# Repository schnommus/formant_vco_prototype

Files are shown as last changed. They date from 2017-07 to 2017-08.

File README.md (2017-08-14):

# SMD Formant VCO Prototype
KiCAD files for eurorack-compatible formant-based VCO design. Mostly created just to learn KiCAD.

Video on construction/operation is here: https://www.youtube.com/watch?v=rq4ovZ2om6k

## ERRATA [V1A] (To be fixed in future revision)
- The TL071 op-amp in the CAD files is arbitrary, I actually used an LM358. Just use whatever 8-pin SOIC dual op-amp you like.
- Diodes (D1..) are incorrect footprint. Change this to suit.
- 10V reference chip, VCC is not connected to +V properly. This must be bridged.
- +/-15V designator actually should be +/-12V to match eurorack. Doesn't make any electrical difference, but it's what the schematic says.
- Be careful with tantalum capacitor orientation, check with schematic. Silkscreen 'line' is negative, not positive.

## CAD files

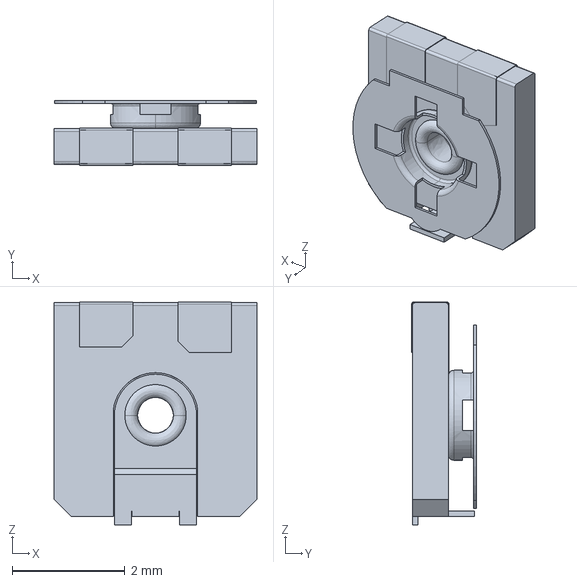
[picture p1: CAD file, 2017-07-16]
models/TC-33X-2.stp
3.60 x 1.15 x 3.96 mm

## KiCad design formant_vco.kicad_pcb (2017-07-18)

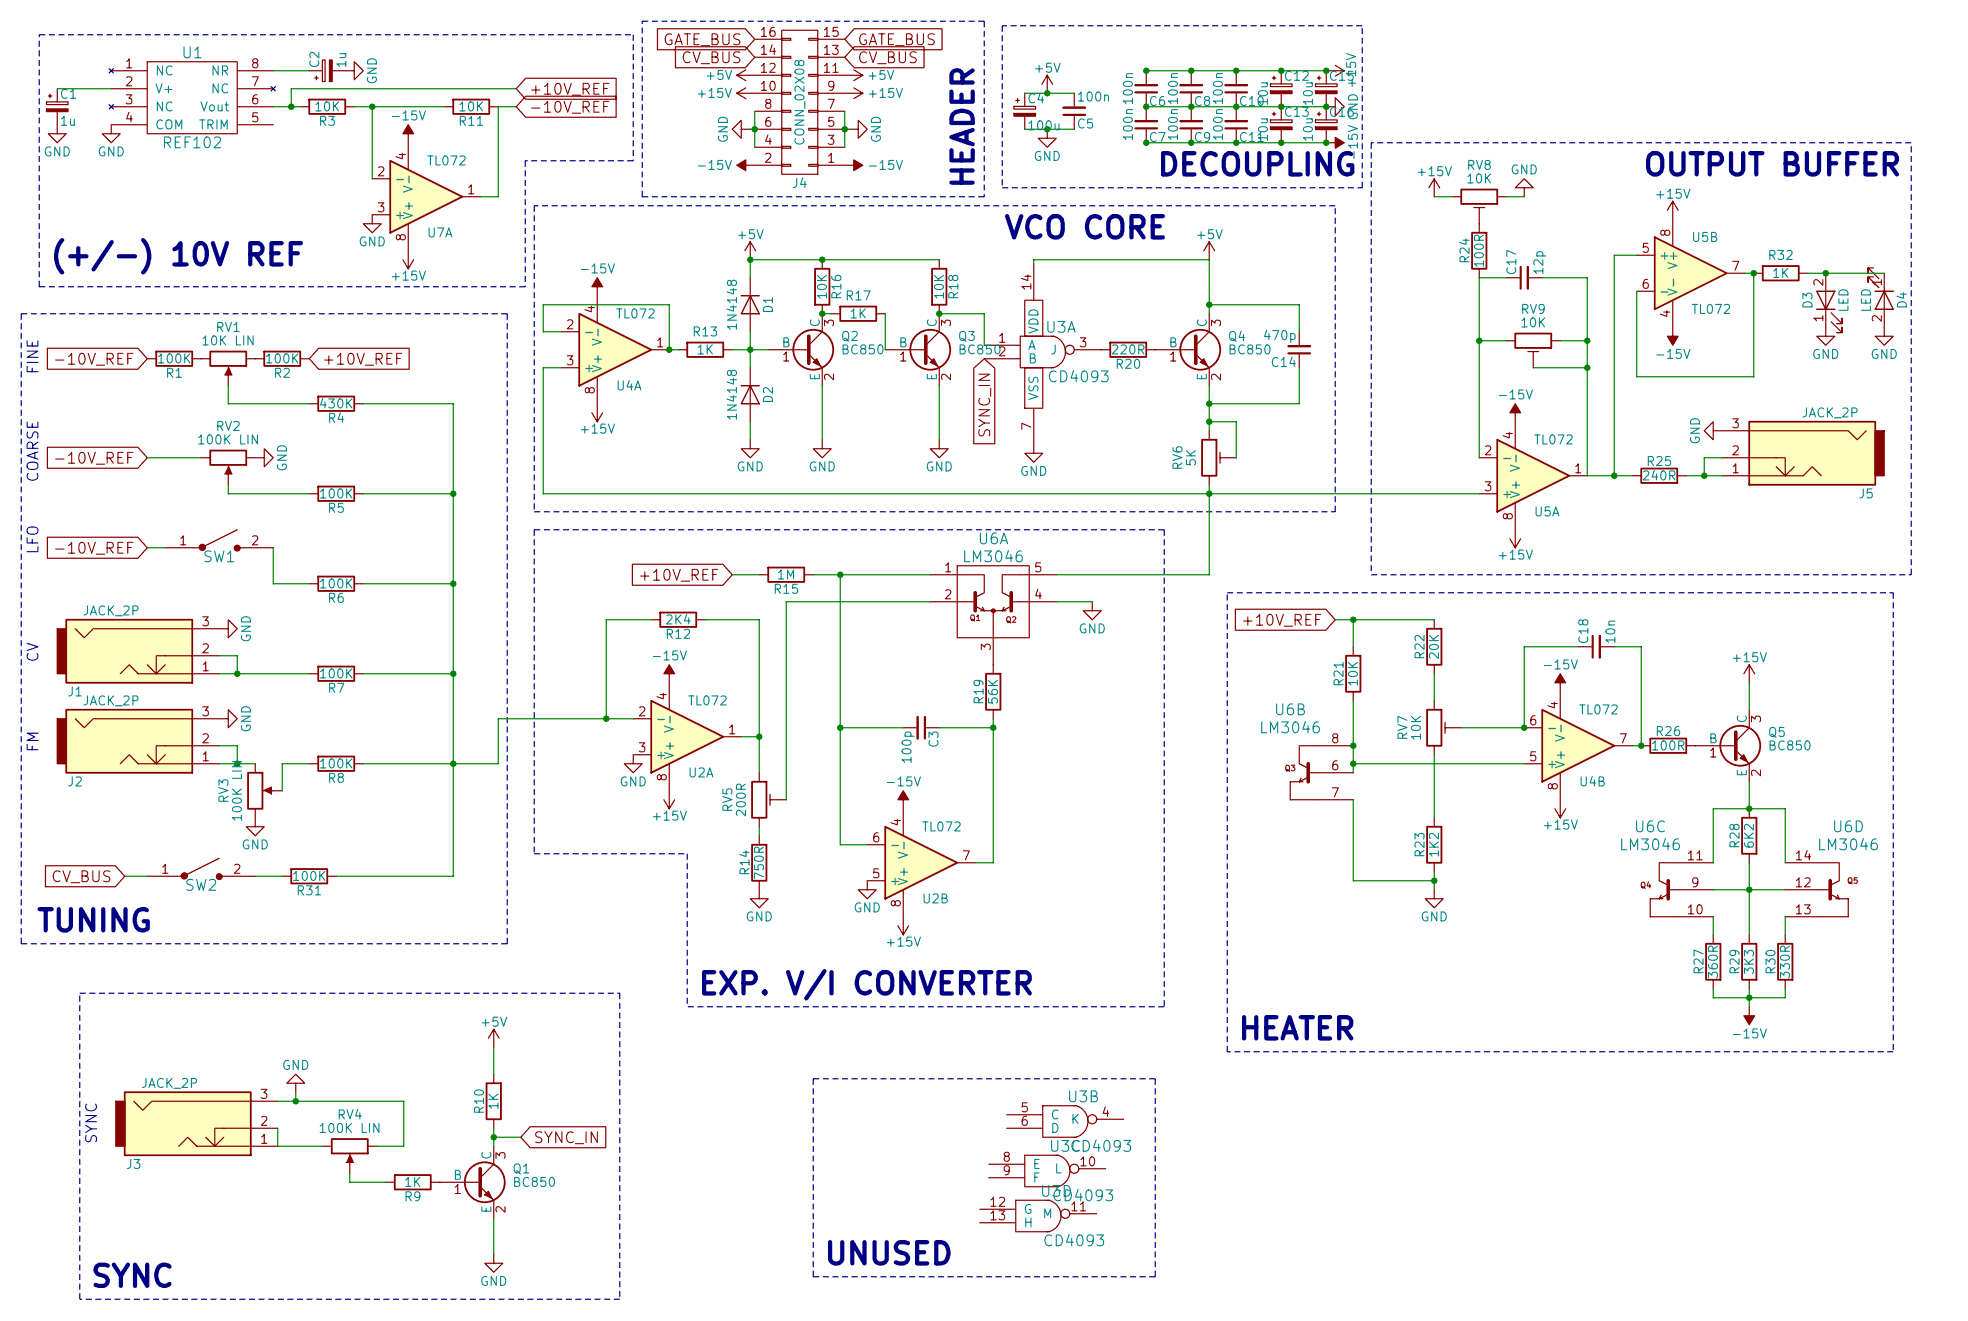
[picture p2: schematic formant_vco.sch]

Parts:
C1, C2: 1u; CP_Tantalum_Case-A_EIA-3216-18_Reflow
C3: 100p; C_0805
C4: 100u; CP_Tantalum_Case-A_EIA-3216-18_Reflow
C5, C6, C7, C8, C9, C10, C11: 100n; C_0805
C12, C13, C15, C16: 10u; CP_Tantalum_Case-A_EIA-3216-18_Reflow
C14: 470p; C_0805
C17: 12p; C_0805
C18: 10n; C_0805
D1, D2: 1N4148; D_0805
D3, D4: LED; LED_D5.0mm
J1, J2, J3, J5: JACK_2P; pj301bm
J4: CONN_02X08; IDC_Header_Straight_16pins
Q1, Q2, Q3, Q4, Q5: BC850; SOT-23
R1, R2, R5, R6, R7, R8, R31: 100K; R_0603
R3, R11, R16, R18, R21: 10K; R_0603
R4: 430K; R_0603
R9, R10, R13, R17, R32: 1K; R_0603
R12: 2K4; R_0603
R14: 750R; R_0603
R15: 1M; R_0603
R19: 56K; R_0603
R20: 220R; R_0603
R22: 20K; R_0603
R23: 1K2; R_0603
R24, R26: 100R; R_0603
R25: 240R; R_0603
R27: 360R; R_0603
R28: 6K2; R_0603
R29: 3K3; R_0603
R30: 330R; R_0603
RV1: 10K LIN; alpha_d_pot_vert
RV2, RV3, RV4: 100K LIN; alpha_d_pot_vert
RV5: 200R; bourns_trimmer_tc33x-2
RV6: 5K; bourns_trimmer_tc33x-2
RV7, RV8, RV9: 10K; bourns_trimmer_tc33x-2
SW1, SW2: SWITCH_SPST; Pin_Header_Straight_2x01_Pitch2.54mm
U1: REF102; SOIC-8_3.9x4.9mm_Pitch1.27mm
U2, U4, U5, U7: TL072; SOIC-8_3.9x4.9mm_Pitch1.27mm
U3: CD4093; SOIC-14_3.9x8.7mm_Pitch1.27mm
U6: LM3046; SOIC-14_3.9x8.7mm_Pitch1.27mm

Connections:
+5V: C4.1, C5.2, C14.2, D1.1 (K), J4.11, J4.12, Q4.3 (C), R10.2, R16.1, R18.1, U3.14 (VDD)
+10V_REF: R2.1, R3.2, R15.2, R21.2, R22.2, U1.6 (Vout)
+15V: C6.2, C8.2, C10.2, C12.1, C15.1, J4.9, J4.10, Q5.3 (C), RV8.3, U2.8 (V+), U4.8 (V+), U5.8 (V+), U7.8 (V+)
-10V_REF: R1.2, R11.1, RV2.3, SW1.1, U7.1
-15V: C7.1, C9.1, C11.1, C13.2, C16.2, J4.1, J4.2, R27.2, R29.2, R30.2, U2.4 (V-), U4.4 (V-), U5.4 (V-), U7.4 (V-)
CV_BUS: J4.13, J4.14, SW2.1
GATE_BUS: J4.15, J4.16
GND: C1.2, C2.2, C4.2, C5.1, C6.1, C7.2, C8.1, C9.2, C10.1, C11.2, C12.2, C13.1, C15.2, C16.1, D2.2 (A), D3.1 (K), D4.2 (A), J1.3, J2.3, J3.3, J4.3, J4.4, J4.5, J4.6, J4.7, J4.8, J5.3, Q1.2 (E), Q2.2 (E), Q3.2 (E), R14.1, R23.1, RV2.1, RV3.3, RV4.1, RV8.1, U1.4 (COM), U2.3 (+), U2.5 (+), U3.7 (VSS), U6.4, U6.7, U7.3 (+)
unnamed: C1.1, U1.2 (V+)
unnamed: C2.1, U1.8 (NR)
unnamed: C3.1, R19.1, U2.7
unnamed: C3.2, R15.1, U2.6 (-), U6.1
unnamed: C14.1, Q4.2 (E), RV6.1, RV6.2
unnamed: C17.1, R24.1, RV9.3, U5.2 (-)
unnamed: C17.2, R25.1, RV9.1, RV9.2, U5.1, U5.5 (+)
unnamed: C18.1, RV7.2, U4.6 (-)
unnamed: C18.2, R26.1, U4.7
unnamed: D1.2 (A), D2.1 (K), Q2.1 (B), R13.1
unnamed: D3.2 (A), D4.1 (K), R32.1
unnamed: J1.1, J1.2, R7.2
unnamed: J2.1, J2.2, RV3.1
unnamed: J3.1, J3.2, RV4.3
unnamed: J5.1, J5.2, R25.2
unnamed: Q1.1 (B), R9.1
unnamed: Q2.3 (C), R16.2, R17.2
unnamed: Q3.1 (B), R17.1
unnamed: Q3.3 (C), R18.2, U3.1 (A)
unnamed: Q4.1 (B), R20.1
unnamed: Q5.1 (B), R26.2
unnamed: Q5.2 (E), R28.1, U6.11, U6.14
unnamed: R1.1, RV1.3
unnamed: R2.2, RV1.1
unnamed: R4.2, RV1.2
unnamed: R5.2, RV2.2
unnamed: R6.2, SW1.2
unnamed: R8.2, RV3.2
unnamed: R9.2, RV4.2
unnamed: R3.1, R11.2, U7.2 (-)
unnamed: R12.1, RV5.1, U2.1
unnamed: R4.1, R5.1, R6.1, R7.1, R8.1, R12.2, R31.1, U2.2 (-)
unnamed: R13.2, U4.1, U4.2 (-)
unnamed: R14.2, RV5.3
unnamed: R19.2, U6.3
unnamed: R20.2, U3.3 (J)
unnamed: R21.1, U4.5 (+), U6.6, U6.8
unnamed: R22.1, RV7.1
unnamed: R23.2, RV7.3
unnamed: R24.2, RV8.2
unnamed: R27.1, U6.10
unnamed: R28.2, R29.1, U6.9, U6.12
unnamed: R30.1, U6.13
unnamed: R31.2, SW2.2
unnamed: R32.2, U5.6 (-), U5.7
unnamed: RV5.2, U6.2
unnamed: RV6.3, U4.3 (+), U5.3 (+), U6.5
SYNC_IN: Q1.3 (C), R10.1, U3.2 (B)

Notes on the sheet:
FINE
COARSE
LFO
SYNC
HEATER
UNUSED
TUNING
(+/-) 10V REF
OUTPUT BUFFER
VCO CORE
EXP. V/I CONVERTER
DECOUPLING
HEADER

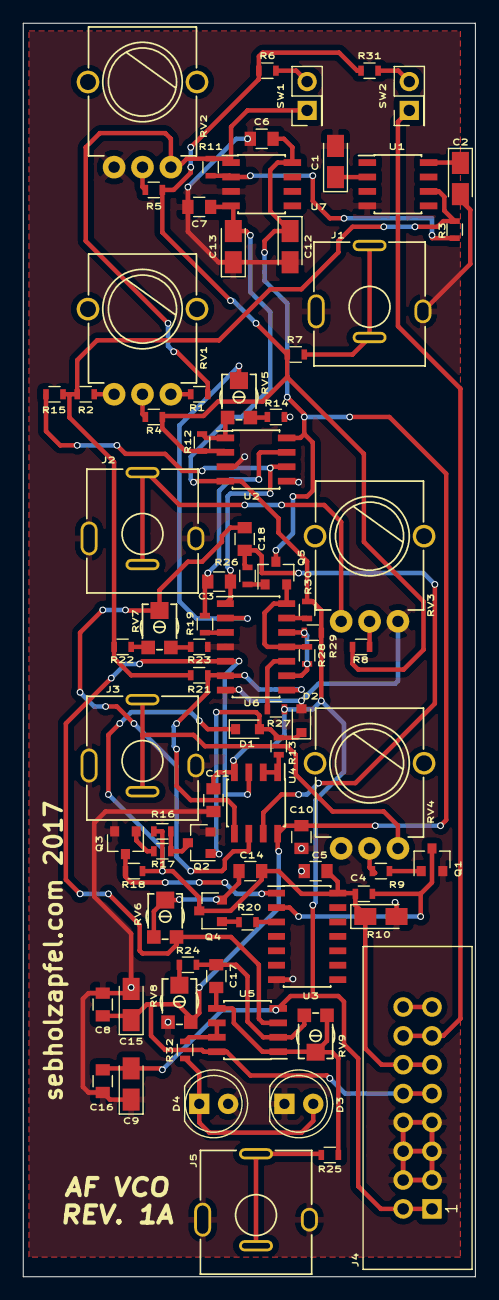
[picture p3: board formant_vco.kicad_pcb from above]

Board: 2 copper layers, 39.8 x 110.4 mm, 82 parts (0 on the bottom side), 56 nets.

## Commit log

2017-07-15 Add eurorack synth power header
    [formant_vco.sch]
2017-07-15 Add output indicator LEDS
    [formant_vco.sch]
2017-07-16 Add footprints for mono jack and alpha pots
    [TC-33X-2.stp, formant_vco.kicad_pcb, formant_vco.sch]
2017-07-16 Swap TL074 for TL072
    [formant_vco.sch]
2017-07-16 Start placing things
    [formant_vco.kicad_pcb, formant_vco.sch]
2017-07-16 place rest of components
    [formant_vco.kicad_pcb, formant_vco.sch]
2017-07-18 Some routing
    [formant_vco.kicad_pcb]
2017-07-18 Final routing, fab outputs
    [formant_vco-B.Cu.gbr, formant_vco-B.Mask.gbr, formant_vco-B.SilkS.gbr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]
